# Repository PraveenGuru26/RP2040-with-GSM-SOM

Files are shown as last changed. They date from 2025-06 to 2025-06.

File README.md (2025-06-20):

# RP2040-with-GSM-SOM
## 📄 Overview
This repository contains the schematic and block design documentation for a custom 4-layer embedded system built around the Raspberry Pi Pico (RP2040). This robust design is tailored for low-power IoT applications requiring reliable communication, data logging, and remote monitoring functionalities.

## Key Components
RP2040 (Raspberry Pi Pico W): Main controller with Wi-Fi capability.
GSM System-on-Module (AS7672S): For remote communication and data transmission.
RS485 Interface: Allows communication with Energy Meters or industrial systems.
SPI Flash (W25Q32JVSSIQ): 32Mbit memory for local data storage.
RTC (DS3231): Real-time clock for time-stamping data.

## Power Circuitry:
24V to 5V DC-DC converter (3A)
LDO regulators for 3.3V and 4V output
TP4056-based Li-ion battery charging
MT3608 Boost converter (3.3V to 5V @ 4A)

## 🔌 Power Supply Logic
Primary power from 24V DC supply.
If DC-DC 5V fails, boost converter activates to maintain operation using battery.
Li-ion battery is continuously charged during regular operation.

## 🔧 Features
🛰️ GNSS Antenna Support for positioning or navigation modules.
🔄 Level Shifters for voltage compatibility between RP2040 and GSM module.
🔐 Optocoupler Isolation for GPIO-based input/output protection.

##🕓 Low Power Design:
Active Transmission: ~2A
Idle Consumption: ~2–5 mA

## 📐 Block Diagram Highlights
Input/Output Protection: Opto-isolated GPIOs for safe field connections.
Connectivity: UART, I2C, SPI, TTL-to-RS485, USB Type-B for debug/power.
SIM Interface: Dual SIM slots (Nano and Micro).
Test Points: Accessible headers for all critical voltages (24V, 5V, 3V3, 4V, GND, VBAT).

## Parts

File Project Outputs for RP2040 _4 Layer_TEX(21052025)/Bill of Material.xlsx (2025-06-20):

Line # | Name | Description | Designator | Revision ID | Revision Status | Manufacturer 1 | Manufacturer Part Number 1 | Manufacturer Lifecycle 1 | Supplier 1 | Supplier Part Number 1 | Supplier Unit Price 1 | Supplier Subtotal 1
 | URB2405YMD-20WR3 | 20W isolated DC-DC converter DIP package, Ultra-wide input and regulated single output | B1 |  |  | TDPOWER | TURB2405YMD-20WR3S | Unknown
 | FOD8314 | Logic Output Optocouplers 1.0A Output Gate Driver Optocoupler | B2 |  |  | ON Semiconductor / Fairchild | FOD8314 | Volume Production | Arrow Electronics | FOD8314 | 0.5898 | 3.54
 | FOD8314 | Logic Output Optocouplers 1.0A Output Gate Driver Optocoupler | B3 |  |  | ON Semiconductor / Fairchild | FOD8314 | Volume Production | Arrow Electronics | FOD8314 | 0.5898 | 3.54
 | FOD8314 | Logic Output Optocouplers 1.0A Output Gate Driver Optocoupler | B4 |  |  | ON Semiconductor / Fairchild | FOD8314 | Volume Production | Arrow Electronics | FOD8314 | 0.5898 | 3.54
 | FOD8314 | Logic Output Optocouplers 1.0A Output Gate Driver Optocoupler | B5 |  |  | ON Semiconductor / Fairchild | FOD8314 | Volume Production | Arrow Electronics | FOD8314 | 0.5898 | 3.54
 | FOD8314 | Logic Output Optocouplers 1.0A Output Gate Driver Optocoupler | B6 |  |  | ON Semiconductor / Fairchild | FOD8314 | Volume Production | Arrow Electronics | FOD8314 | 0.5898 | 3.54
 | FOD8314 | Logic Output Optocouplers 1.0A Output Gate Driver Optocoupler | B7 |  |  | ON Semiconductor / Fairchild | FOD8314 | Volume Production | Arrow Electronics | FOD8314 | 0.5898 | 3.54
 | MT3608 | High Efficiency 1.2MHz 2A Step Up Converter | B8 |  |  | Olimex | PACKOF10PCSMT3608 | Unknown
 | GRT31CR61H106ME01L | CAP CER 10UF 50V X5R 1206 | C1 | CMP-06035-048951-1 | Up to date | Murata | GRT31CR61H106ME01L | Volume Production
 | TCA1A226M8R | 22ÂµF Molded Tantalum Capacitors 10V 1206 (3216 Metric) | C2
 | GRT31CR61H106ME01L | CAP CER 10UF 50V X5R 1206 | C3 | CMP-06035-048951-1 | Up to date | Murata | GRT31CR61H106ME01L | Volume Production
 | GRT31CR61H106ME01L | CAP CER 10UF 50V X5R 1206 | C4 | CMP-06035-048951-1 | Up to date | Murata | GRT31CR61H106ME01L | Volume Production
 | GRT31CR61H106ME01L | CAP CER 10UF 50V X5R 1206 | C5 | CMP-06035-048951-1 | Up to date | Murata | GRT31CR61H106ME01L | Volume Production
 | T491A106K010AT | Capacitor, Tantalum, 10 uF, +/- 10%, 10 V, -55 to 125 degC, 2-Pin SMD (1206), RoHS, Tape and Reel | C6 | CMP-2000-05172-1 | Up to date | KEMET | T491A106K010AT | Volume Production | Newark | 57K1635 | 0.34 | 0.34
 | CL05A106MP5NUNC | CAP CER 10UF 10V X5R 0402 | C7 | CMP-13271-000002-1 | Up to date | Samsung | CL05A106MP5NUNC | Volume Production | Newark | 82AC9189 | 0.08 | 0.08
 | HHXC500ARA101MJA0G | CAP ALUM POLY 100UF 20% 50V SMD | C8 | CMP-33769-000007-1 | Up to date | United Chemi-Con | HHXC500ARA101MJA0G | Unknown | Mouser | 661-HHXC500A101MJA0G | 1.34 | 1.34
 | GRT31CR61H106ME01L | CAP CER 10UF 50V X5R 1206 | C9 | CMP-06035-048951-1 | Up to date | Murata | GRT31CR61H106ME01L | Volume Production
 | C0402C104K8PACTU | CAP CER 0.1UF 10V X5R 0402 | C10 | CMP-2008-02046-2 | Up to date | KEMET | C0402C104K8PACTU | Volume Production | Newark | 78H4791 | 0.007 | 0.014
 | Capacitor 1nF +/-20% 50V 0402 | Chip Capacitor, 1nF +/-20%, 50V, 0402, Thickness 0.33 mm | C11 | CMP-001-00066-3 | Up to date | Wurth Electronics | 885012205061 | Volume Production | Newark | 75Y6020 | 0.007 | 0.014
 | Capacitor 470pF +/-20% 50V 0402 | Chip Capacitor, 470pF +/-20%, 50V, 0402, Thickness 0.6 mm | C12 | CMP-001-00068-4 | Up to date | Kyocera AVX | 04025C471KAT2A | Volume Production | Avnet | 96M1170 | 0.007 | 0.007
 | Capacitor 1nF +/-20% 50V 0402 | Chip Capacitor, 1nF +/-20%, 50V, 0402, Thickness 0.33 mm | C13 | CMP-001-00066-3 | Up to date | Wurth Electronics | 885012205061 | Volume Production | Newark | 75Y6020 | 0.007 | 0.014
 | C0402C104K4RACTU |  | C14 | CMP-0001-00074-2 | Up to date | Taiyo Yuden | EMK105B7104KV-F | Volume Production | Mouser | 963-EMK105B7104KV-F | 0.016 | 0.16
 | C0402C104K4RACTU |  | C15 | CMP-0001-00074-2 | Up to date | Taiyo Yuden | EMK105B7104KV-F | Volume Production | Mouser | 963-EMK105B7104KV-F | 0.016 | 0.16
 | GRM1555C1H101JA01D |  | C16 | CMP-2008-03915-1 | Up to date | Murata | GRM1555C1H101JA01D | Not Recommended for New Design | Newark | 94AK6918 | 0.008 | 0.08
 | C0402C104K4RACTU |  | C17 | CMP-0001-00074-2 | Up to date | Taiyo Yuden | EMK105B7104KV-F | Volume Production | Mouser | 963-EMK105B7104KV-F | 0.016 | 0.16
 | 04025A330JAT2A | General Purpose Ceramic Capacitor, 0402, 33pF, 5%, C0G, 30ppm/°C, 50V | C18 | CMP-2008-02637-2 | Up to date | Kyocera AVX | 04025A330JAT2A | Volume Production | Farnell | 1327636 | 0.01642 | 0.1642
 | Capacitor 1µF +/-20% 10V 0402 | Chip Capacitor, 1µF +/-20%, 10V, 0402, Thickness 0.6 mm | C19 | CMP-001-00063-3 | Up to date | Kyocera AVX | 0402ZD105KAT2A | Volume Production | Newark | 06M4041 | 0.029 | 0.116
 | C0402C104K4RACTU |  | C20 | CMP-0001-00074-2 | Up to date | Taiyo Yuden | EMK105B7104KV-F | Volume Production | Mouser | 963-EMK105B7104KV-F | 0.016 | 0.16
 | Capacitor 10 pF +/- 0.25 pF 50 V 0402 | Chip Capacitor, 10 pF, +/- 0.25 pF, 50 V, 0402 (1005 Metric) | C21 | CMP-001-00011-6 | Up to date | Kyocera AVX | 04025A100JAT2A | Volume Production | Newark | 96M1128 | 0.005 | 0.005
 | GRM32ER60J107ME20L | CAP CER 100UF 6.3V X5R 1210 | C22 | CMP-2000-05259-2 | Up to date | Murata | GRM32ER60J107ME20L | Not Recommended for New Design | Future Electronics | 2114105 | 1.29 | 2.58
 | GRM32ER60J107ME20L | CAP CER 100UF 6.3V X5R 1210 | C23 | CMP-2000-05259-2 | Up to date | Murata | GRM32ER60J107ME20L | Not Recommended for New Design | Future Electronics | 2114105 | 1.29 | 2.58
 | 04025A330JAT2A | General Purpose Ceramic Capacitor, 0402, 33pF, 5%, C0G, 30ppm/°C, 50V | C24 | CMP-2008-02637-2 | Up to date | Kyocera AVX | 04025A330JAT2A | Volume Production | Farnell | 1327636 | 0.01642 | 0.1642
 | 04025A330JAT2A | General Purpose Ceramic Capacitor, 0402, 33pF, 5%, C0G, 30ppm/°C, 50V | C25 | CMP-2008-02637-2 | Up to date | Kyocera AVX | 04025A330JAT2A | Volume Production | Farnell | 1327636 | 0.01642 | 0.1642
 | 04025A330JAT2A | General Purpose Ceramic Capacitor, 0402, 33pF, 5%, C0G, 30ppm/°C, 50V | C26 | CMP-2008-02637-2 | Up to date | Kyocera AVX | 04025A330JAT2A | Volume Production | Farnell | 1327636 | 0.01642 | 0.1642
 | C0402C104K4RACTU |  | C27 | CMP-0001-00074-2 | Up to date | Taiyo Yuden | EMK105B7104KV-F | Volume Production | Mouser | 963-EMK105B7104KV-F | 0.016 | 0.16
 | C0402C104K4RACTU |  | C28 | CMP-0001-00074-2 | Up to date | Taiyo Yuden | EMK105B7104KV-F | Volume Production | Mouser | 963-EMK105B7104KV-F | 0.016 | 0.16
 | GRT31CR61H106ME01L | CAP CER 10UF 50V X5R 1206 | C29 | CMP-06035-048951-1 | Up to date | Murata | GRT31CR61H106ME01L | Volume Production
 | GRT31CR61H106ME01L | CAP CER 10UF 50V X5R 1206 | C30 | CMP-06035-048951-1 | Up to date | Murata | GRT31CR61H106ME01L | Volume Production
 | C0402C104K4RACTU |  | C31 | CMP-0001-00074-2 | Up to date | Taiyo Yuden | EMK105B7104KV-F | Volume Production | Mouser | 963-EMK105B7104KV-F | 0.016 | 0.16
 | C0402C104K4RACTU |  | C32 | CMP-0001-00074-2 | Up to date | Taiyo Yuden | EMK105B7104KV-F | Volume Production | Mouser | 963-EMK105B7104KV-F | 0.016 | 0.16
 | Capacitor 1µF +/-20% 10V 0402 | Chip Capacitor, 1µF +/-20%, 10V, 0402, Thickness 0.6 mm | C33 | CMP-001-00063-3 | Up to date | Kyocera AVX | 0402ZD105KAT2A | Volume Production | Newark | 06M4041 | 0.029 | 0.116
 | Capacitor 1µF +/-20% 10V 0402 | Chip Capacitor, 1µF +/-20%, 10V, 0402, Thickness 0.6 mm | C34 | CMP-001-00063-3 | Up to date | Kyocera AVX | 0402ZD105KAT2A | Volume Production | Newark | 06M4041 | 0.029 | 0.116
 | Capacitor 1µF +/-20% 10V 0402 | Chip Capacitor, 1µF +/-20%, 10V, 0402, Thickness 0.6 mm | C35 | CMP-001-00063-3 | Up to date | Kyocera AVX | 0402ZD105KAT2A | Volume Production | Newark | 06M4041 | 0.029 | 0.116
 | C0402C104K8PACTU | CAP CER 0.1UF 10V X5R 0402 | C36 | CMP-2008-02046-2 | Up to date | KEMET | C0402C104K8PACTU | Volume Production | Newark | 78H4791 | 0.007 | 0.014
 | 61900211121 | CONN HEADER VERT 2POS 2.54MM | CN1 | CMP-1502-00584-2 | Out of date | Wurth Electronics | 61900211121 | Volume Production | Newark | 16T0681 | 0.079 | 0.158
 | 61900211121 | CONN HEADER VERT 2POS 2.54MM | CN2 | CMP-1502-00584-2 | Out of date | Wurth Electronics | 61900211121 | Volume Production | Newark | 16T0681 | 0.079 | 0.158
 | LTST-C230KRKT | LED RED CLEAR CHIP SMD | D1 | CMP-22017-000041-1 | Up to date | Vishay Lite-On | LTST-C230KRKT | Volume Production | Mouser | 859-LTST-C230KRKT | 0.16 | 0.48
 | LTST-C230KRKT | LED RED CLEAR CHIP SMD | D2 | CMP-22017-000041-1 | Up to date | Vishay Lite-On | LTST-C230KRKT | Volume Production | Mouser | 859-LTST-C230KRKT | 0.16 | 0.48
 | 1N4007 SMD | Rectifier, 1Kv, 1A, Do-214Ac Rohs Compliant: Yes | D3 | CMP-12389-000001-1 | Up to date | Multicomp | 1N4007 SMD | Not Recommended for New Design
 | P6KE36ARLG | 600 W Peak Power Transient Voltage Suppressor, 2-Pin Surmetic(TM) 40, Pb-Free, Tape and Reel | D4 | CMP-1061-00690-1 | Up to date | onsemi | P6KE36ARLG | Volume Production
 | ESDA25P35-1U1M | TVS DIODE 22V 41V 1610 | D5 | CMP-004-00023-3 | Up to date | STMicroelectronics | ESDA25P35-1U1M | Volume Production | Newark | 12AC9615 | 0.091 | 0.091
 | SMBJ28CA | TVS DIODE 28V 45.4V DO214AA | D6 | CMP-08607-000057-1 | Up to date | Littelfuse | SMBJ28CA | Volume Production | Arrow Electronics | SMBJ28CA | 0.3393 | 1.02
 | SS34-E3/57T | Diode Schottky 40 V 3A Surface Mount DO-214AB (SMC) | D7
 | SMCJ60A | Transient Voltage Suppression Diode, 60 V, -65 to 150 degC, 2-Pin DO-214AB (SMCJ), RoHS, Tape and Reel | D8 | CMP-2000-07111-1 | Up to date | Littelfuse | SMCJ6.0A | Volume Production | Arrow Electronics | SMCJ6.0A | 0.2711 | 1.36
 | SMCJ60A | Transient Voltage Suppression Diode, 60 V, -65 to 150 degC, 2-Pin DO-214AB (SMCJ), RoHS, Tape and Reel | D9 | CMP-2000-07111-1 | Up to date | Littelfuse | SMCJ6.0A | Volume Production | Arrow Electronics | SMCJ6.0A | 0.2711 | 1.36
 | SMCJ60A | Transient Voltage Suppression Diode, 60 V, -65 to 150 degC, 2-Pin DO-214AB (SMCJ), RoHS, Tape and Reel | D10 | CMP-2000-07111-1 | Up to date | Littelfuse | SMCJ6.0A | Volume Production | Arrow Electronics | SMCJ6.0A | 0.2711 | 1.36
 | SMBJ28CA | TVS DIODE 28V 45.4V DO214AA | D11 | CMP-08607-000057-1 | Up to date | Littelfuse | SMBJ28CA | Volume Production | Arrow Electronics | SMBJ28CA | 0.3393 | 1.02
 | SMCJ60A | Transient Voltage Suppression Diode, 60 V, -65 to 150 degC, 2-Pin DO-214AB (SMCJ), RoHS, Tape and Reel | D12 | CMP-2000-07111-1 | Up to date | Littelfuse | SMCJ6.0A | Volume Production | Arrow Electronics | SMCJ6.0A | 0.2711 | 1.36
 | SMBJ28CA | TVS DIODE 28V 45.4V DO214AA | D13 | CMP-08607-000057-1 | Up to date | Littelfuse | SMBJ28CA | Volume Production | Arrow Electronics | SMBJ28CA | 0.3393 | 1.02
 | APHHS1005CGCK | LED GREEN CLEAR CHIP SMD | D14 | CMP-44529-000044-1 | Up to date | Kingbright | APHHS1005CGCK | Volume Production | Digikey | 754-1101-6-ND | 0.26 | 0.26
 | SMCJ60A | Transient Voltage Suppression Diode, 60 V, -65 to 150 degC, 2-Pin DO-214AB (SMCJ), RoHS, Tape and Reel | D15 | CMP-2000-07111-1 | Up to date | Littelfuse | SMCJ6.0A | Volume Production | Arrow Electronics | SMCJ6.0A | 0.2711 | 1.36
 | ESDALC5-1BM2 | Single Line Low Capacitance Transil™, 5 V, -55 to 150 degC, 2-Pin SOD-882, RoHS, Tape and Reel | D16 | CMP-004-00030-3 | Up to date | STMicroelectronics | ESDALC5-1BM2 | Not Recommended for New Design | Mouser | 511-ESDALC5-1BM2 | 0.096 | 0.96
 | ESDALC5-1BM2 | Single Line Low Capacitance Transil™, 5 V, -55 to 150 degC, 2-Pin SOD-882, RoHS, Tape and Reel | D17 | CMP-004-00030-3 | Up to date | STMicroelectronics | ESDALC5-1BM2 | Not Recommended for New Design | Mouser | 511-ESDALC5-1BM2 | 0.096 | 0.96
 | ESDALC5-1BM2 | Single Line Low Capacitance Transil™, 5 V, -55 to 150 degC, 2-Pin SOD-882, RoHS, Tape and Reel | D18 | CMP-004-00030-3 | Up to date | STMicroelectronics | ESDALC5-1BM2 | Not Recommended for New Design | Mouser | 511-ESDALC5-1BM2 | 0.096 | 0.96
 | ESDALC5-1BM2 | Single Line Low Capacitance Transil™, 5 V, -55 to 150 degC, 2-Pin SOD-882, RoHS, Tape and Reel | D19 | CMP-004-00030-3 | Up to date | STMicroelectronics | ESDALC5-1BM2 | Not Recommended for New Design | Mouser | 511-ESDALC5-1BM2 | 0.096 | 0.96
 | ESDALC5-1BM2 | Single Line Low Capacitance Transil™, 5 V, -55 to 150 degC, 2-Pin SOD-882, RoHS, Tape and Reel | D20 | CMP-004-00030-3 | Up to date | STMicroelectronics | ESDALC5-1BM2 | Not Recommended for New Design | Mouser | 511-ESDALC5-1BM2 | 0.096 | 0.96
 | ESDALC5-1BM2 | Single Line Low Capacitance Transil™, 5 V, -55 to 150 degC, 2-Pin SOD-882, RoHS, Tape and Reel | D21 | CMP-004-00030-3 | Up to date | STMicroelectronics | ESDALC5-1BM2 | Not Recommended for New Design | Mouser | 511-ESDALC5-1BM2 | 0.096 | 0.96
 | ESDALC5-1BM2 | Single Line Low Capacitance Transil™, 5 V, -55 to 150 degC, 2-Pin SOD-882, RoHS, Tape and Reel | D22 | CMP-004-00030-3 | Up to date | STMicroelectronics | ESDALC5-1BM2 | Not Recommended for New Design | Mouser | 511-ESDALC5-1BM2 | 0.096 | 0.96
 | ESDALC5-1BM2 | Single Line Low Capacitance Transil™, 5 V, -55 to 150 degC, 2-Pin SOD-882, RoHS, Tape and Reel | D23 | CMP-004-00030-3 | Up to date | STMicroelectronics | ESDALC5-1BM2 | Not Recommended for New Design | Mouser | 511-ESDALC5-1BM2 | 0.096 | 0.96
 | LTST-C230KRKT | LED RED CLEAR CHIP SMD | DS1 | CMP-22017-000041-1 | Up to date | Vishay Lite-On | LTST-C230KRKT | Volume Production | Mouser | 859-LTST-C230KRKT | 0.16 | 0.48
 | TLMS1100-GS08 | Red Led, 20mA, 2.1 V, -40 to 100 degC, 2-Pin SMD (0603), RoHS, Tape and Reel | DS2 | CMP-007-00030-2 | Up to date | Vishay | TLMS1100-GS08 | Unknown
 | TLMS1100-GS08 | Red Led, 20mA, 2.1 V, -40 to 100 degC, 2-Pin SMD (0603), RoHS, Tape and Reel | DS3 | CMP-007-00030-2 | Up to date | Vishay | TLMS1100-GS08 | Unknown
 | TLMS1100-GS08 | Red Led, 20mA, 2.1 V, -40 to 100 degC, 2-Pin SMD (0603), RoHS, Tape and Reel | DS4 | CMP-007-00030-2 | Up to date | Vishay | TLMS1100-GS08 | Unknown
 | TLMS1100-GS08 | Red Led, 20mA, 2.1 V, -40 to 100 degC, 2-Pin SMD (0603), RoHS, Tape and Reel | DS5 | CMP-007-00030-2 | Up to date | Vishay | TLMS1100-GS08 | Unknown
 | TLMS1100-GS08 | Red Led, 20mA, 2.1 V, -40 to 100 degC, 2-Pin SMD (0603), RoHS, Tape and Reel | DS6 | CMP-007-00030-2 | Up to date | Vishay | TLMS1100-GS08 | Unknown
 | TLMS1100-GS08 | Red Led, 20mA, 2.1 V, -40 to 100 degC, 2-Pin SMD (0603), RoHS, Tape and Reel | DS7 | CMP-007-00030-2 | Up to date | Vishay | TLMS1100-GS08 | Unknown
 | TLMS1100-GS08 | Red Led, 20mA, 2.1 V, -40 to 100 degC, 2-Pin SMD (0603), RoHS, Tape and Reel | DS8 | CMP-007-00030-2 | Up to date | Vishay | TLMS1100-GS08 | Unknown
 | TLMS1100-GS08 | Red Led, 20mA, 2.1 V, -40 to 100 degC, 2-Pin SMD (0603), RoHS, Tape and Reel | DS10 | CMP-007-00030-2 | Up to date | Vishay | TLMS1100-GS08 | Unknown
 | TLMS1100-GS08 | Red Led, 20mA, 2.1 V, -40 to 100 degC, 2-Pin SMD (0603), RoHS, Tape and Reel | DS11 | CMP-007-00030-2 | Up to date | Vishay | TLMS1100-GS08 | Unknown
 | TLMS1100-GS08 | Red Led, 20mA, 2.1 V, -40 to 100 degC, 2-Pin SMD (0603), RoHS, Tape and Reel | DS12 | CMP-007-00030-2 | Up to date | Vishay | TLMS1100-GS08 | Unknown
 | TLMS1100-GS08 | Red Led, 20mA, 2.1 V, -40 to 100 degC, 2-Pin SMD (0603), RoHS, Tape and Reel | DS13 | CMP-007-00030-2 | Up to date | Vishay | TLMS1100-GS08 | Unknown
 | TLMS1100-GS08 | Red Led, 20mA, 2.1 V, -40 to 100 degC, 2-Pin SMD (0603), RoHS, Tape and Reel | DS14 | CMP-007-00030-2 | Up to date | Vishay | TLMS1100-GS08 | Unknown
 | TLMS1100-GS08 | Red Led, 20mA, 2.1 V, -40 to 100 degC, 2-Pin SMD (0603), RoHS, Tape and Reel | DS15 | CMP-007-00030-2 | Up to date | Vishay | TLMS1100-GS08 | Unknown
 | TLMS1100-GS08 | Red Led, 20mA, 2.1 V, -40 to 100 degC, 2-Pin SMD (0603), RoHS, Tape and Reel | DS16 | CMP-007-00030-2 | Up to date | Vishay | TLMS1100-GS08 | Unknown
 | BLM21PG300SN1D | Chip Ferrite Bead, 0805, 30Ω @ 100MHz, 0.014Ω, , 4A | FB1 | CMP-0686-00620-3 | Up to date | Murata | BLM21PG300SN1D | Volume Production | Digikey | 490-1052-1-ND | 0.11 | 0.11
 | MIC29302WU | Linear Voltage Regulator IC Positive Adjustable 1 Output 3A TO-263-5 | IC2
 | 1725656 | Male Header, Pitch 2.54 mm, 1 x 2 Position, Height 9 mm, Tail Length 3.5 mm | J1 | CMP-2000-05299-1 | Up to date | Phoenix Contact | 1725656 | Volume Production | Mouser | 651-1725656 | 1.67 | 3.34
 | 2336582-1 | PUSH-PUSH NANO SIM CONNECTOR | J2 |  |  | TE Connectivity | 2336582-1 | Volume Production | Digikey | 17-2336582-1CT-ND | 2.25 | 2.25
 | 1932788-1 |  | J3 |  |  | TE Connectivity | 1932788-1 | Volume Production | Arrow Electronics | 1932788-1 | 0.7242 | 0.7242
 | 1725656 | Male Header, Pitch 2.54 mm, 1 x 2 Position, Height 9 mm, Tail Length 3.5 mm | J5 | CMP-2000-05299-1 | Up to date | Phoenix Contact | 1725656 | Volume Production | Mouser | 651-1725656 | 1.67 | 3.34
 | MTSW-102-X-X-D-X |  | J7
 | CONREVSMA002-G | RP-SMA Female Right-Angle Through-Hole Mount Connector, Gold | J8 |  |  | Linx | CONREVSMA002-G | Unknown | Digikey | CONREVSMA002-G-ND | 3.74 | 7.48
 | CONREVSMA002-G | RP-SMA Female Right-Angle Through-Hole Mount Connector, Gold | J9 |  |  | Linx | CONREVSMA002-G | Unknown | Digikey | CONREVSMA002-G-ND | 3.74 | 7.48
 | 796683-9 | 9 Position Wire to Board Terminal Block Horizontal with Board 0.197 (5.00mm) Through Hole | J11 |  |  | TE Connectivity | 796683-9 | Volume Production | Digikey | A136648-ND | 8.84 | 8.84
 | 796683-8 |  | J12 |  |  | TE Connectivity | 796683-8 | Volume Production | Mouser | 571-796683-8 | 4.28 | 4.28
 | LQW15AN47NG00D | Wire Wound RF Inductor 47nH ±2% 210mA 1.08Ω 0402 (1005) | L1 | CMP-06042-006618-1 | Up to date | Murata | LQW15AN47NG00D | Not Recommended for New Design | Mouser | 81-LQW15AN47NG00D | 0.11 | 0.11
 | CDRH104RNP-220NC_22uH | Fixed Inductors 22uH 2.5A | L2
 | 61300211121 |  | P2 | CMP-1712-00002-6 | Up to date | Wurth Electronics | 61300211121 | Volume Production | Digikey | 732-5315-ND | 0.12 | 0.24
 | 61300211121 |  | P3 | CMP-1712-00002-6 | Up to date | Wurth Electronics | 61300211121 | Volume Production | Digikey | 732-5315-ND | 0.12 | 0.24
 | 653002114822 |  | P4 | CMP-1502-00739-2 | Up to date | Wurth Electronics | 653002114822 | Unknown | Farnell | 3818290 | 0.38132 | 3.81
 | 61300311121 |  | P5 | CMP-1502-01062-3 | Up to date | Wurth Electronics | 61300311121 | Volume Production | Digikey | 732-5316-ND | 0.12 | 0.12
 | 0ZCG0050AF2C | PTC RESET FUSE 30V 500MA 1812 | PTC_F1
 | FOD817D3SD | OPTOISOLATOR 5KV TRANSISTOR 4SMD | Q1 | CMP-07144-000021-1 | Up to date | ON Semiconductor / Fairchild | FOD817D3SD | Volume Production | Digikey | FOD817D3SDCT-ND | 0.48 | 0.48
 | BSS138 | N-Channel 50V 220mA (Ta) 360mW (Ta) Surface Mount SOT-23-3 | Q2
 | MJD50T4G | High Voltage Power Transistor, 3-Pin DPAK, Pb-Free, Tape and Reel | Q3 | CMP-1048-00190-1 | Up to date | onsemi | MJD50T4G | Volume Production | Mouser | 863-MJD50T4G | 0.9 | 1.8
 | MJD50T4G | High Voltage Power Transistor, 3-Pin DPAK, Pb-Free, Tape and Reel | Q4 | CMP-1048-00190-1 | Up to date | onsemi | MJD50T4G | Volume Production | Mouser | 863-MJD50T4G | 0.9 | 1.8
 | BSS138 | N-Channel 50V 220mA (Ta) 360mW (Ta) Surface Mount SOT-23-3 | Q5
 | TLP290-4(TP,E | OPTOISOLTR 2.5KV 4CH TRANS 16-SO | Q6 | CMP-35887-000006-1 | Up to date | Toshiba | TLP290-4(TP,E | Volume Production | Digikey | TLP290-4(TPECT-ND | 1.54 | 3.08
 | FSB560A | FSB560A Bipolar Transistors - BJT NPN Transistor Low Saturation | Q7 | CMP-00278-84328379-1 | Up to date | ON Semiconductor / Fairchild | FSB560A | Volume Production | Mouser | 512-FSB560A | 0.62 | 1.24
 | TLP290-4(TP,E | OPTOISOLTR 2.5KV 4CH TRANS 16-SO | Q8 | CMP-35887-000006-1 | Up to date | Toshiba | TLP290-4(TP,E | Volume Production | Digikey | TLP290-4(TPECT-ND | 1.54 | 3.08
 | FSB560A | FSB560A Bipolar Transistors - BJT NPN Transistor Low Saturation | Q9 | CMP-00278-84328379-1 | Up to date | ON Semiconductor / Fairchild | FSB560A | Volume Production | Mouser | 512-FSB560A | 0.62 | 1.24
 | Resistor 0R +/- 5% 1206 250 mW | Chip Resistor, 0 Ohm, +/- 5%, 0.25 W, -55 to 155 degC, 1206 (3216 Metric) | R1 | CMP-009-00002-5 | Up to date | Yageo | RC1206JR-070RL | Volume Production | Farnell | 9240276 | 0.01533 | 0.42936
 | Resistor 0R +/- 5% 1206 250 mW | Chip Resistor, 0 Ohm, +/- 5%, 0.25 W, -55 to 155 degC, 1206 (3216 Metric) | R2 | CMP-009-00002-5 | Up to date | Yageo | RC1206JR-070RL | Volume Production | Farnell | 9240276 | 0.01533 | 0.42936
 | Resistor 0R +/- 5% 1206 250 mW | Chip Resistor, 0 Ohm, +/- 5%, 0.25 W, -55 to 155 degC, 1206 (3216 Metric) | R3 | CMP-009-00002-5 | Up to date | Yageo | RC1206JR-070RL | Volume Production | Farnell | 9240276 | 0.01533 | 0.42936
 | Resistor 0R +/- 5% 1206 250 mW | Chip Resistor, 0 Ohm, +/- 5%, 0.25 W, -55 to 155 degC, 1206 (3216 Metric) | R4 | CMP-009-00002-5 | Up to date | Yageo | RC1206JR-070RL | Volume Production | Farnell | 9240276 | 0.01533 | 0.42936
 | Resistor 0R +/- 5% 1206 250 mW | Chip Resistor, 0 Ohm, +/- 5%, 0.25 W, -55 to 155 degC, 1206 (3216 Metric) | R5 | CMP-009-00002-5 | Up to date | Yageo | RC1206JR-070RL | Volume Production | Farnell | 9240276 | 0.01533 | 0.42936
 | ERJ-2RKF1910X |  | R6 | CMP-1011-00427-2 | Up to date | Panasonic | ERJ-2RKF1910X | Volume Production | Avnet | 53W4258 | 0.004 | 0.004
 | CPF0402B187RE1 |  | R7 | CMP-2002-03161-1 | Up to date | TE Connectivity | CPF0402B187RE1 | Volume Production | Mouser | 279-CPF0402B187RE1 | 0.29 | 0.29
 | Resistor 4k7 +/-1% 0402 100 mW | Chip Resistor, 4.7 KOhm, +/- 1%, 0.1 W, -55 to 155 degC, 0402 (1005 Metric) | R8 | CMP-009-00030-5 | Up to date | Panasonic | ERJ-2RKF4701X | Volume Production | Mouser | 667-ERJ-2RKF4701X | 0.023 | 0.23
 | Resistor 4k7 +/-1% 0402 100 mW | Chip Resistor, 4.7 KOhm, +/- 1%, 0.1 W, -55 to 155 degC, 0402 (1005 Metric) | R9 | CMP-009-00030-5 | Up to date | Panasonic | ERJ-2RKF4701X | Volume Production | Mouser | 667-ERJ-2RKF4701X | 0.023 | 0.23
 | Resistor 1k +/-1% 0402 100 mW | Chip Resistor, 1 KOhm, +/- 1%, 0.1 W, -55 to 155 degC, 0402 (1005 Metric) | R10 | CMP-009-00009-5 | Up to date | Panasonic | ERJ-2RKF1001X | Volume Production | Newark | 85Y8051 | 0.1 | 0.1
 | Resistor 4k7 +/-1% 0402 100 mW | Chip Resistor, 4.7 KOhm, +/- 1%, 0.1 W, -55 to 155 degC, 0402 (1005 Metric) | R11 | CMP-009-00030-5 | Up to date | Panasonic | ERJ-2RKF4701X | Volume Production | Mouser | 667-ERJ-2RKF4701X | 0.023 | 0.23
 | RC0402FR-0710KL |  | R12 | CMP-2002-07353-1 | Up to date | Yageo | RC0402FR-0710KL | Volume Production
 | Resistor 4k7 +/-1% 0402 100 mW | Chip Resistor, 4.7 KOhm, +/- 1%, 0.1 W, -55 to 155 degC, 0402 (1005 Metric) | R13 | CMP-009-00030-5 | Up to date | Panasonic | ERJ-2RKF4701X | Volume Production | Mouser | 667-ERJ-2RKF4701X | 0.023 | 0.23
 | RC0402FR-0710KL |  | R14 | CMP-2002-07353-1 | Up to date | Yageo | RC0402FR-0710KL | Volume Production
 | RC0402FR-0710KL |  | R15 | CMP-2002-07353-1 | Up to date | Yageo | RC0402FR-0710KL | Volume Production
 | RC0402FR-0710KL |  | R16 | CMP-2002-07353-1 | Up to date | Yageo | RC0402FR-0710KL | Volume Production
 | Resistor 4k7 +/-1% 0402 100 mW | Chip Resistor, 4.7 KOhm, +/- 1%, 0.1 W, -55 to 155 degC, 0402 (1005 Metric) | R17 | CMP-009-00030-5 | Up to date | Panasonic | ERJ-2RKF4701X | Volume Production | Mouser | 667-ERJ-2RKF4701X | 0.023 | 0.23
 | Resistor 4k7 +/-1% 0402 100 mW | Chip Resistor, 4.7 KOhm, +/- 1%, 0.1 W, -55 to 155 degC, 0402 (1005 Metric) | R18 | CMP-009-00030-5 | Up to date | Panasonic | ERJ-2RKF4701X | Volume Production | Mouser | 667-ERJ-2RKF4701X | 0.023 | 0.23
 | Resistor 100K +/-1 % 0402 63 mW | Chip Resistor, 100 kOhms, +/-1 %, 63 mW, -55 to 155 degC, 0402 | R19 | CMP-009-00168-3 | Up to date | Bourns | CR0402-FX-1003GLF | Volume Production | Newark | 79AK8869 | 0.002 | 0.008
 | Resistor 100K +/-1 % 0402 63 mW | Chip Resistor, 100 kOhms, +/-1 %, 63 mW, -55 to 155 degC, 0402 | R20 | CMP-009-00168-3 | Up to date | Bourns | CR0402-FX-1003GLF | Volume Production | Newark | 79AK8869 | 0.002 | 0.008
 | Resistor 0R 0402 63 mW | Chip Resistor, 0 Ohm, 0.063 W, -55 to 155 degC, 0402 (1005 Metric) | R21 | CMP-009-00004-5 | Up to date | Yageo | RC0402JR-070RL | Volume Production | Newark | 98K7493 | 0.003 | 0.03
 | Resistor 0R 0402 63 mW | Chip Resistor, 0 Ohm, 0.063 W, -55 to 155 degC, 0402 (1005 Metric) | R22 | CMP-009-00004-5 | Up to date | Yageo | RC0402JR-070RL | Volume Production | Newark | 98K7493 | 0.003 | 0.03
 | Resistor 0R 0402 63 mW | Chip Resistor, 0 Ohm, 0.063 W, -55 to 155 degC, 0402 (1005 Metric) | R23 | CMP-009-00004-5 | Up to date | Yageo | RC0402JR-070RL | Volume Production | Newark | 98K7493 | 0.003 | 0.03
 | Resistor 10k +/-1% 0402 100 mW | Chip Resistor, 10 KOhm, +/- 1%, 0.1 W, -55 to 155 degC, 0402 (1005 Metric) | R24 | CMP-009-00015-5 | Up to date | Panasonic | ERJ-2RKF1002X | Volume Production | Newark | 64R5248 | 0.1 | 0.1
 | Resistor 100K +/-1 % 0402 63 mW | Chip Resistor, 100 kOhms, +/-1 %, 63 mW, -55 to 155 degC, 0402 | R25 | CMP-009-00168-3 | Up to date | Bourns | CR0402-FX-1003GLF | Volume Production | Newark | 79AK8869 | 0.002 | 0.008
 | Resistor 100K +/-1 % 0402 63 mW | Chip Resistor, 100 kOhms, +/-1 %, 63 mW, -55 to 155 degC, 0402 | R26 | CMP-009-00168-3 | Up to date | Bourns | CR0402-FX-1003GLF | Volume Production | Newark | 79AK8869 | 0.002 | 0.008
 | Resistor 0R +/- 5% 1206 250 mW | Chip Resistor, 0 Ohm, +/- 5%, 0.25 W, -55 to 155 degC, 1206 (3216 Metric) | R27 | CMP-009-00002-5 | Up to date | Yageo | RC1206JR-070RL | Volume Production | Farnell | 9240276 | 0.01533 | 0.42936
 | Resistor 0R +/- 5% 1206 250 mW | Chip Resistor, 0 Ohm, +/- 5%, 0.25 W, -55 to 155 degC, 1206 (3216 Metric) | R28 | CMP-009-00002-5 | Up to date | Yageo | RC1206JR-070RL | Volume Production | Farnell | 9240276 | 0.01533 | 0.42936
 | Resistor 0R +/- 5% 1206 250 mW | Chip Resistor, 0 Ohm, +/- 5%, 0.25 W, -55 to 155 degC, 1206 (3216 Metric) | R29 | CMP-009-00002-5 | Up to date | Yageo | RC1206JR-070RL | Volume Production | Farnell | 9240276 | 0.01533 | 0.42936
 | Resistor 0R +/- 5% 1206 250 mW | Chip Resistor, 0 Ohm, +/- 5%, 0.25 W, -55 to 155 degC, 1206 (3216 Metric) | R30 | CMP-009-00002-5 | Up to date | Yageo | RC1206JR-070RL | Volume Production | Farnell | 9240276 | 0.01533 | 0.42936
 | Resistor 0R +/- 5% 1206 250 mW | Chip Resistor, 0 Ohm, +/- 5%, 0.25 W, -55 to 155 degC, 1206 (3216 Metric) | R31 | CMP-009-00002-5 | Up to date | Yageo | RC1206JR-070RL | Volume Production | Farnell | 9240276 | 0.01533 | 0.42936
 | Resistor 0R +/- 5% 1206 250 mW | Chip Resistor, 0 Ohm, +/- 5%, 0.25 W, -55 to 155 degC, 1206 (3216 Metric) | R32 | CMP-009-00002-5 | Up to date | Yageo | RC1206JR-070RL | Volume Production | Farnell | 9240276 | 0.01533 | 0.42936
 | Resistor 0R +/- 5% 1206 250 mW | Chip Resistor, 0 Ohm, +/- 5%, 0.25 W, -55 to 155 degC, 1206 (3216 Metric) | R33 | CMP-009-00002-5 | Up to date | Yageo | RC1206JR-070RL | Volume Production | Farnell | 9240276 | 0.01533 | 0.42936
 | Resistor 0R +/- 5% 1206 250 mW | Chip Resistor, 0 Ohm, +/- 5%, 0.25 W, -55 to 155 degC, 1206 (3216 Metric) | R34 | CMP-009-00002-5 | Up to date | Yageo | RC1206JR-070RL | Volume Production | Farnell | 9240276 | 0.01533 | 0.42936
 | Resistor 0R +/- 5% 1206 250 mW | Chip Resistor, 0 Ohm, +/- 5%, 0.25 W, -55 to 155 degC, 1206 (3216 Metric) | R35 | CMP-009-00002-5 | Up to date | Yageo | RC1206JR-070RL | Volume Production | Farnell | 9240276 | 0.01533 | 0.42936
 | RC0603FR-07220RL | General Purpose Chip Resistors, 220 Ohm, +/- 1%, -55 to 155 degC, 0603 (1608 Metric), RoHS, Tape and Reel | R36 | CMP-1659-00018-2 | Up to date | Yageo | RC0603FR-07220RL | Volume Production | Mouser | 603-RC0603FR-07220RL | 0.009 | 0.09
 | Resistor 0R +/- 5% 1206 250 mW | Chip Resistor, 0 Ohm, +/- 5%, 0.25 W, -55 to 155 degC, 1206 (3216 Metric) | R37 | CMP-009-00002-5 | Up to date | Yageo | RC1206JR-070RL | Volume Production | Farnell | 9240276 | 0.01533 | 0.42936
 | Resistor 0R +/- 5% 1206 250 mW | Chip Resistor, 0 Ohm, +/- 5%, 0.25 W, -55 to 155 degC, 1206 (3216 Metric) | R38 | CMP-009-00002-5 | Up to date | Yageo | RC1206JR-070RL | Volume Production | Farnell | 9240276 | 0.01533 | 0.42936
 | RC0603FR-07220RL | General Purpose Chip Resistors, 220 Ohm, +/- 1%, -55 to 155 degC, 0603 (1608 Metric), RoHS, Tape and Reel | R39 | CMP-1659-00018-2 | Up to date | Yageo | RC0603FR-07220RL | Volume Production | Mouser | 603-RC0603FR-07220RL | 0.009 | 0.09
 | RC0603FR-07220RL | General Purpose Chip Resistors, 220 Ohm, +/- 1%, -55 to 155 degC, 0603 (1608 Metric), RoHS, Tape and Reel | R40 | CMP-1659-00018-2 | Up to date | Yageo | RC0603FR-07220RL | Volume Production | Mouser | 603-RC0603FR-07220RL | 0.009 | 0.09
 | RC0603FR-07220RL | General Purpose Chip Resistors, 220 Ohm, +/- 1%, -55 to 155 degC, 0603 (1608 Metric), RoHS, Tape and Reel | R41 | CMP-1659-00018-2 | Up to date | Yageo | RC0603FR-07220RL | Volume Production | Mouser | 603-RC0603FR-07220RL | 0.009 | 0.09
 | RC0603FR-07220RL | General Purpose Chip Resistors, 220 Ohm, +/- 1%, -55 to 155 degC, 0603 (1608 Metric), RoHS, Tape and Reel | R42 | CMP-1659-00018-2 | Up to date | Yageo | RC0603FR-07220RL | Volume Production | Mouser | 603-RC0603FR-07220RL | 0.009 | 0.09
 | Resistor 0R +/- 5% 1206 250 mW | Chip Resistor, 0 Ohm, +/- 5%, 0.25 W, -55 to 155 degC, 1206 (3216 Metric) | R43 | CMP-009-00002-5 | Up to date | Yageo | RC1206JR-070RL | Volume Production | Farnell | 9240276 | 0.01533 | 0.42936
 | Resistor 0R +/- 5% 1206 250 mW | Chip Resistor, 0 Ohm, +/- 5%, 0.25 W, -55 to 155 degC, 1206 (3216 Metric) | R44 | CMP-009-00002-5 | Up to date | Yageo | RC1206JR-070RL | Volume Production | Farnell | 9240276 | 0.01533 | 0.42936
 | RC0603FR-07220RL | General Purpose Chip Resistors, 220 Ohm, +/- 1%, -55 to 155 degC, 0603 (1608 Metric), RoHS, Tape and Reel | R45 | CMP-1659-00018-2 | Up to date | Yageo | RC0603FR-07220RL | Volume Production | Mouser | 603-RC0603FR-07220RL | 0.009 | 0.09
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

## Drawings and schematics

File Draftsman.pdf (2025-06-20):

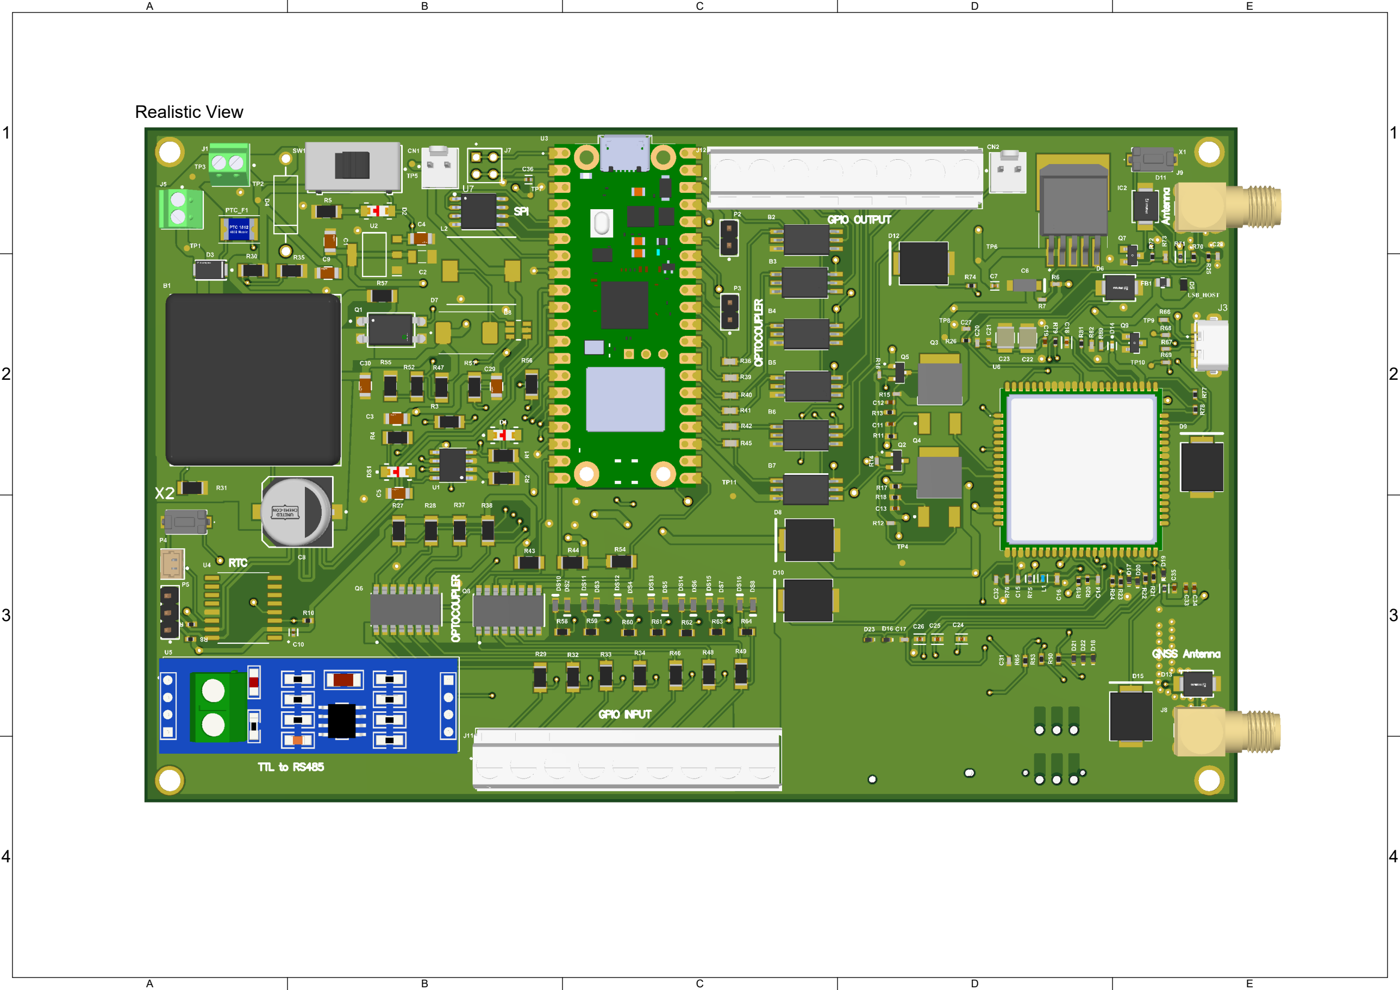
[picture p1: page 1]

A

B

C

D

E

1 | 1
2 | 2
3 | 3
4 | 4

Realistic View

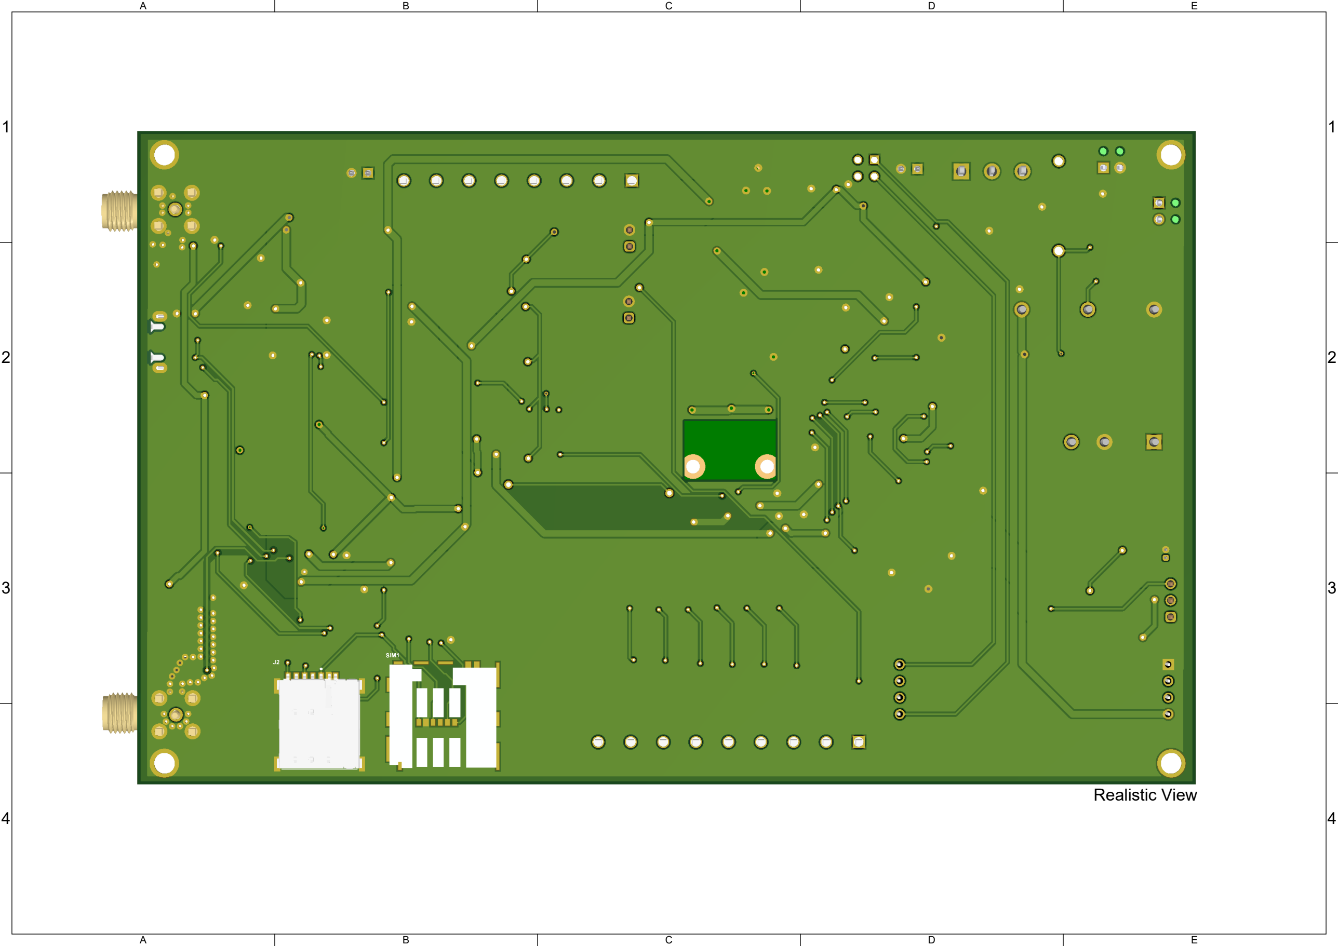
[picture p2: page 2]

1 | 1
2 | 2
3 | 3
4 | 4

Realistic View

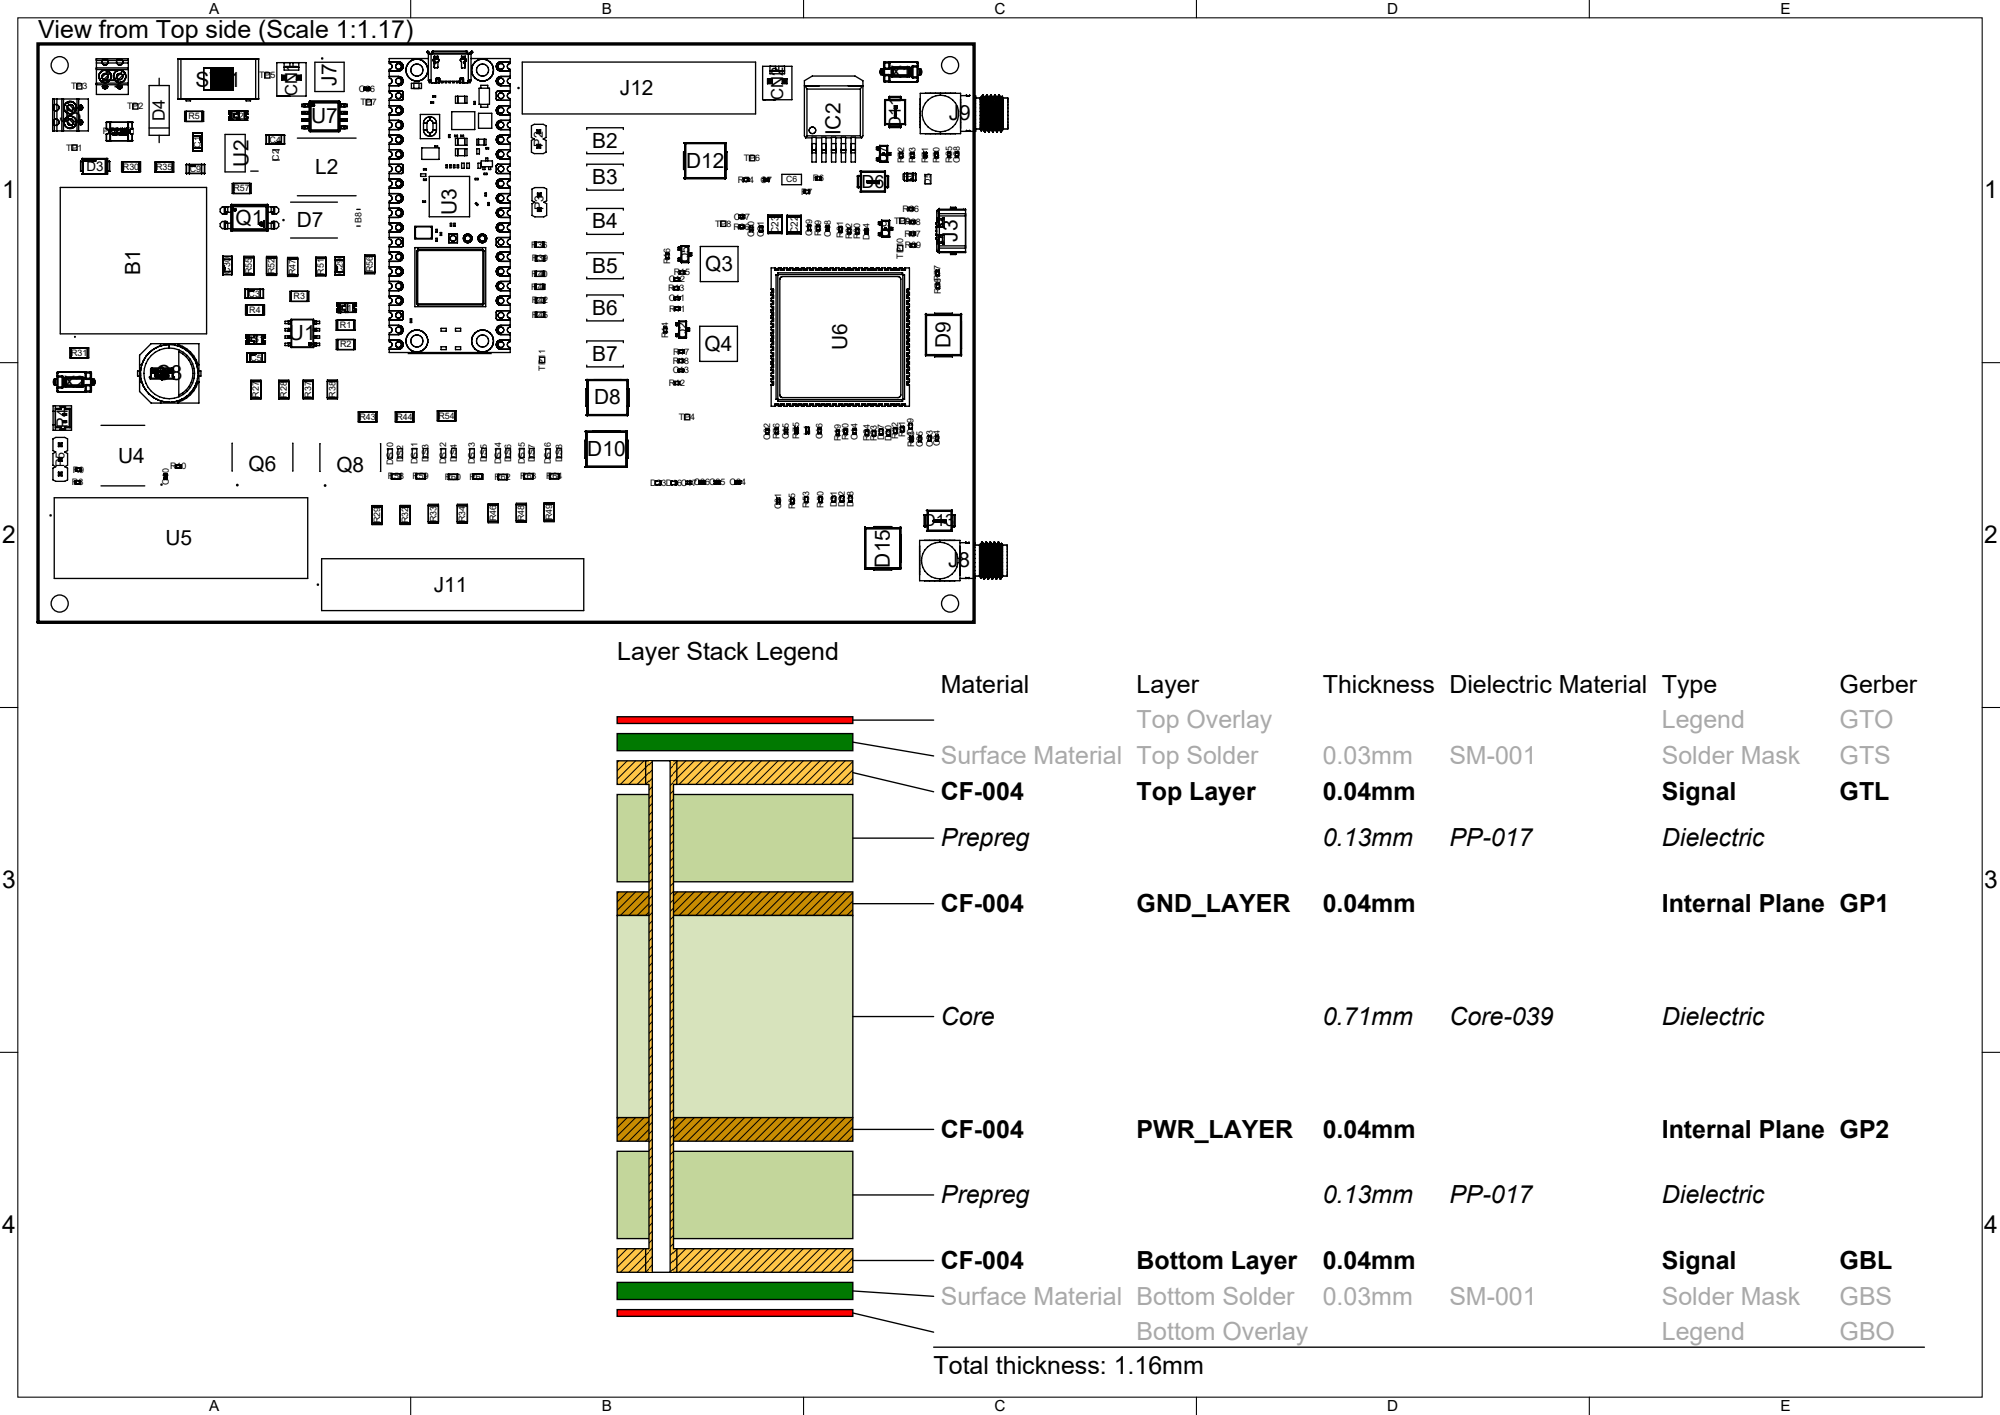
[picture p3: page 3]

View from Top side (Scale 1:1.17)

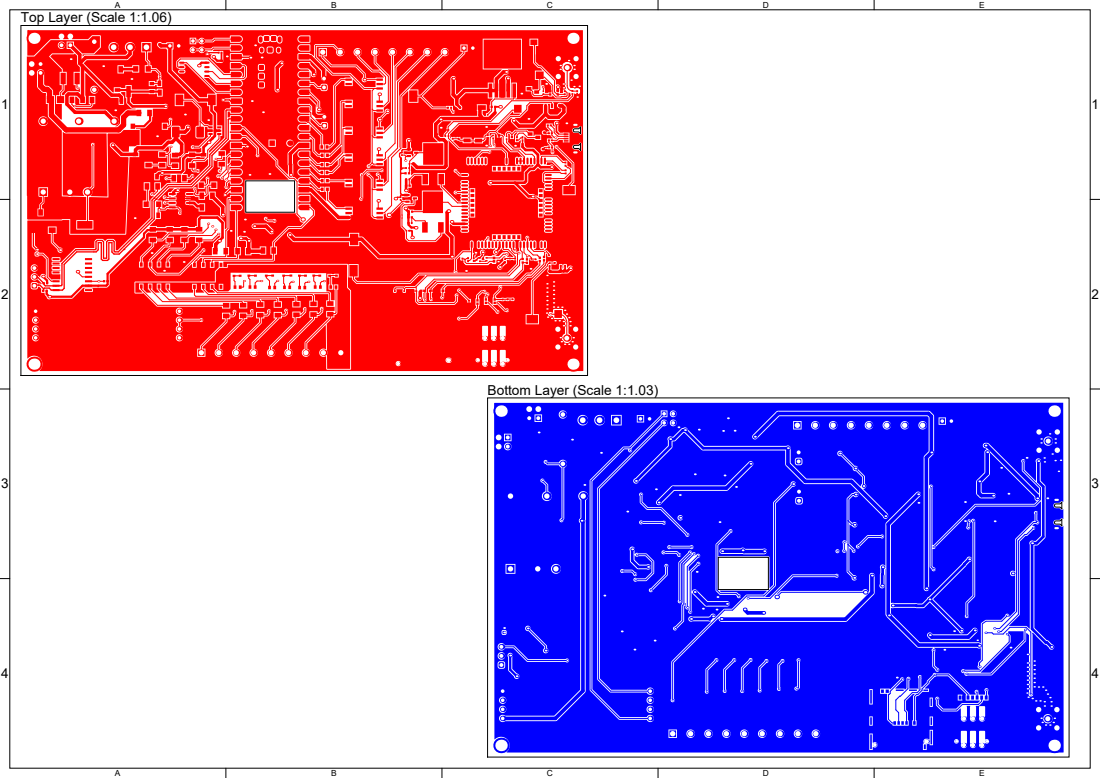
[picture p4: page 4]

Top Layer (Scale 1:1.06)

Bottom Layer (Scale 1:1.03)

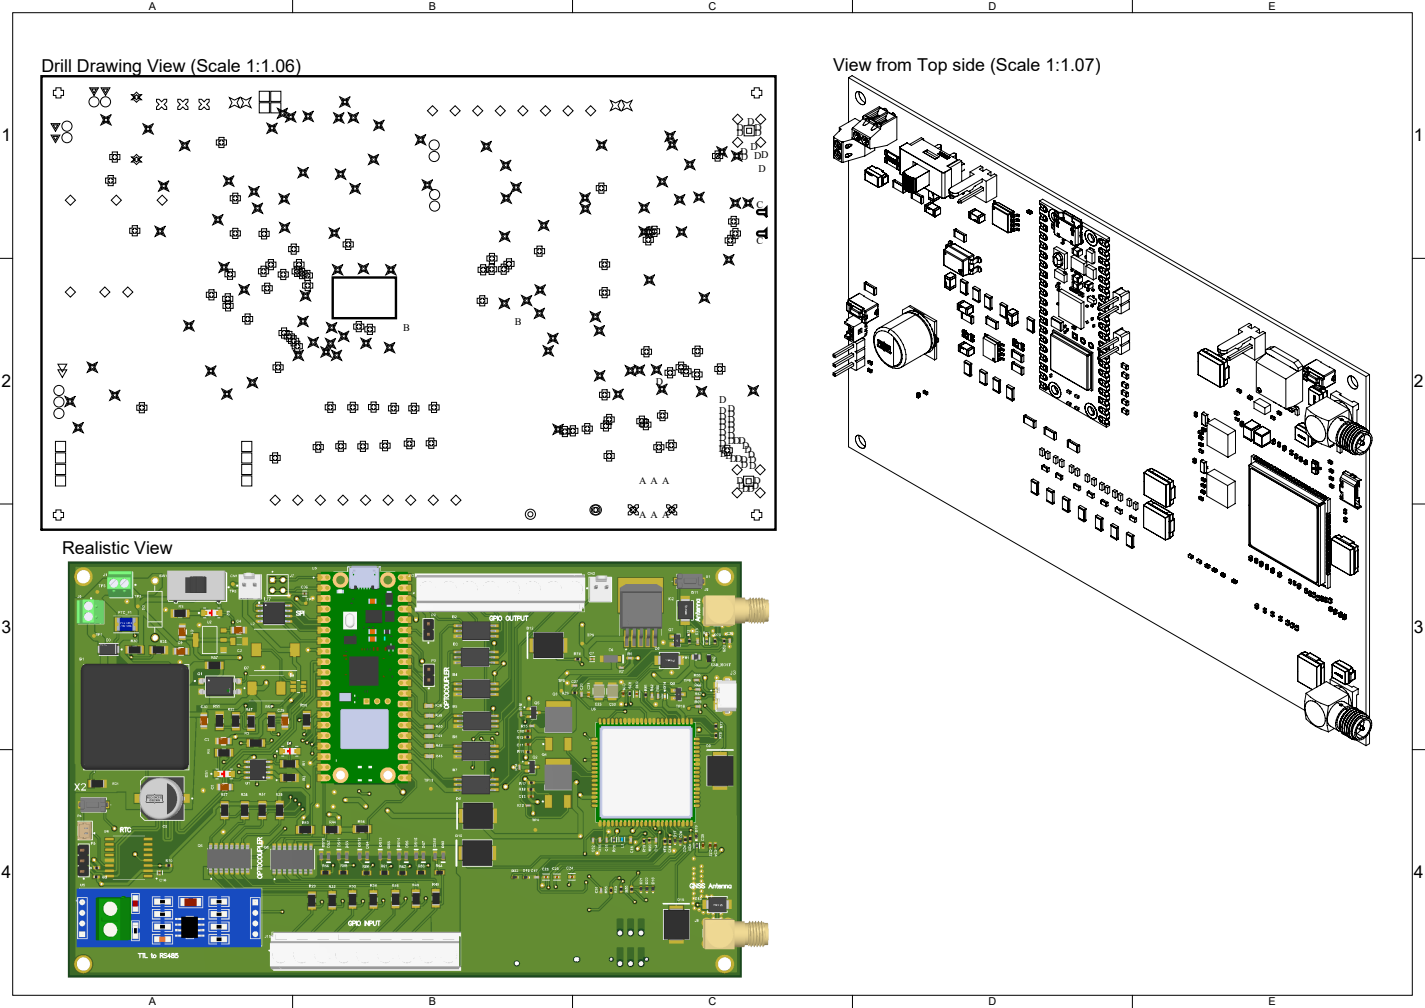
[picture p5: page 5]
DDD; D D D D D D D D D DDDDD D D DD; DDD DDD DDDDDD; Drill Drawing View (Scale 1:1.06); View from Top side (Scale 1:1.07); Realistic View
